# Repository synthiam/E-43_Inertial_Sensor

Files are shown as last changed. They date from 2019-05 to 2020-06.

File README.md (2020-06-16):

# E-43 Inertial Sensor

**Project Status:** Ready to manufacture

If you are new to GitHub and would like to create a derivative of this project, please have a look at GitHub instructions to [fork a repo](https://help.github.com/en/articles/fork-a-repo)

## Description

Out of our passion to solve the issue of time waste in the robot creation process, ARC was born. The ARC software platform reduces the time it takes to get from idea to implementation. Since 2011 we have been listening to the challenges robot builders encounter and continue to provide them with an ever expanding toolbox of solutions. Join us on this journey!

We didn't stop at the software, we also made time saving hardware solutions. This is an accelerometer/gyro/temperature sensor paired with an STM32 ARM cortex-M0 microcontroller. The microcontroller simplifies the sensor data and makes it compatible with ARC. A unique feature of this design is that it connects directly to a visual interface and automatically outputs pitch and roll angles in ARC. We want to share these files with you so you can create your own version for your community and customers to enjoy!

**Features:** 
- 3-axis Gyroscope/Accelerometer
- Temperature sensor
- I2C communication
- Mini programming header
- 5V tolerant I/O pins
- Blue LED status indicator
- ARC skill available 
- Voltage requirement: 3.2-3.4VDC (3.3V Typical)
- Current draw: 10.8mA
- Dimensions: 15.8(W) x 38.7(L) x 7.5(H) (mm)
- Weight: 3g

**Major components:** 
- STM32F030C8T6 32-bit Cortex-M0 ARM microcontroller (custom firmware provided)
- LSM6DS3USTR Accelerometer/Gyro Combo 

**Manufacturing notes:** 
1. Supplier: programs custom firmware into the STM32F030C8T6 at their facility before sending to manufacturer
2. Manufacturer: Single side placement and soldering of SMT components

## Contents

[**Documentation:**](https://github.com/synthiam/E-43_Inertial_Sensor/tree/master/E-43%20Documentation) Schematic PDF, Datasheet PDF, BOM, Test Procedures

[**Hardware:**](https://github.com/synthiam/E-43_Inertial_Sensor/tree/master/E-43%20Hardware) Altium PCB design File, Altium SCH Design File, Gerbers

[**Firmware:**](https://github.com/synthiam/E-43_Inertial_Sensor/tree/master/E-43%20Firmware) Code, Compiled Binary

*Altium Libraries are also available <a href="https://github.com/synthiam/Synthiam_Altium_Librairies">here</a>*

## Photos

<p align="left">

</p>

## Contact

For profit use of these files requires written consent. Contact partners@synthiam.com. For everyone else, party on!

For support check out our Synthiam Community: https://synthiam.com/Community

## License

This project is released under the following licenses:

**Hardware:** Creative Commons Plus Attribution-NonCommercial 4.0 International (CC+ BY-NC 4.0)

**Firmware:** Apache 2.0 + “Commons Clause” License Condition v1.0

Please see [LICENSE.md](https://github.com/synthiam/E-43_Inertial_Sensor/blob/master/LICENSE.md) for license details.



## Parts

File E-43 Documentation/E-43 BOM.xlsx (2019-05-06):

Qty | Description | Manufacturer Part No. | Alternative | Designator | Custom Information | Link
E-43 Interial Sensor
1 | 2 layer, Blue soldermask, White silkscreen, ENIG | Inertial Sensor Board |  | PCB
1 | STmicro MCU 32bit 64KB Flash 48LQFP | STM32F030C8T6 |  | U1 | Needs custom Firmware programmed into chip | https://www.digikey.ca/product-detail/en/stmicroelectronics/STM32F030C8T6/497-14043-ND/4357252
1 | White 0805 LED | QBLP631-IW |  | LED |  | http://www.digikey.ca/product-detail/en/0/1516-1085-1-ND
4 | 0.1uF 0603 Ceramic Capacitor | C0603C104K4RACTU |  | C1, C2, C3, C4
2 | FERRITE BEAD 30 OHM 0603 | CIC10P300NC |  | L1, L2 |  | https://www.digikey.ca/product-detail/en/samsung-electro-mechanics/CIC10P300NC/1276-6322-1-ND/3973802
2 | 4.7kohm 4 x Resistor Array | EXB-38V472JV |  | RA1, RA2
1 | 330ohm Resistor 0603 1/10W | RC0603FR-07330RL |  | R1
1 | STmicro Accelerometer/Gyro Combo | LSM6DS3USTR |  | U2 |  | https://www.digikey.ca/product-detail/en/stmicroelectronics/LSM6DS3USTR/497-16910-1-ND/6229964
1 | 4-pin 2mm pitch JST-PH SMD connector | S4B-PH-SM4-TB(LF)(SN) |  | P1 |  | http://www.digikey.ca/product-detail/en/S4B-PH-SM4-TB(LF)(SN)/455-1751-1-ND/926848

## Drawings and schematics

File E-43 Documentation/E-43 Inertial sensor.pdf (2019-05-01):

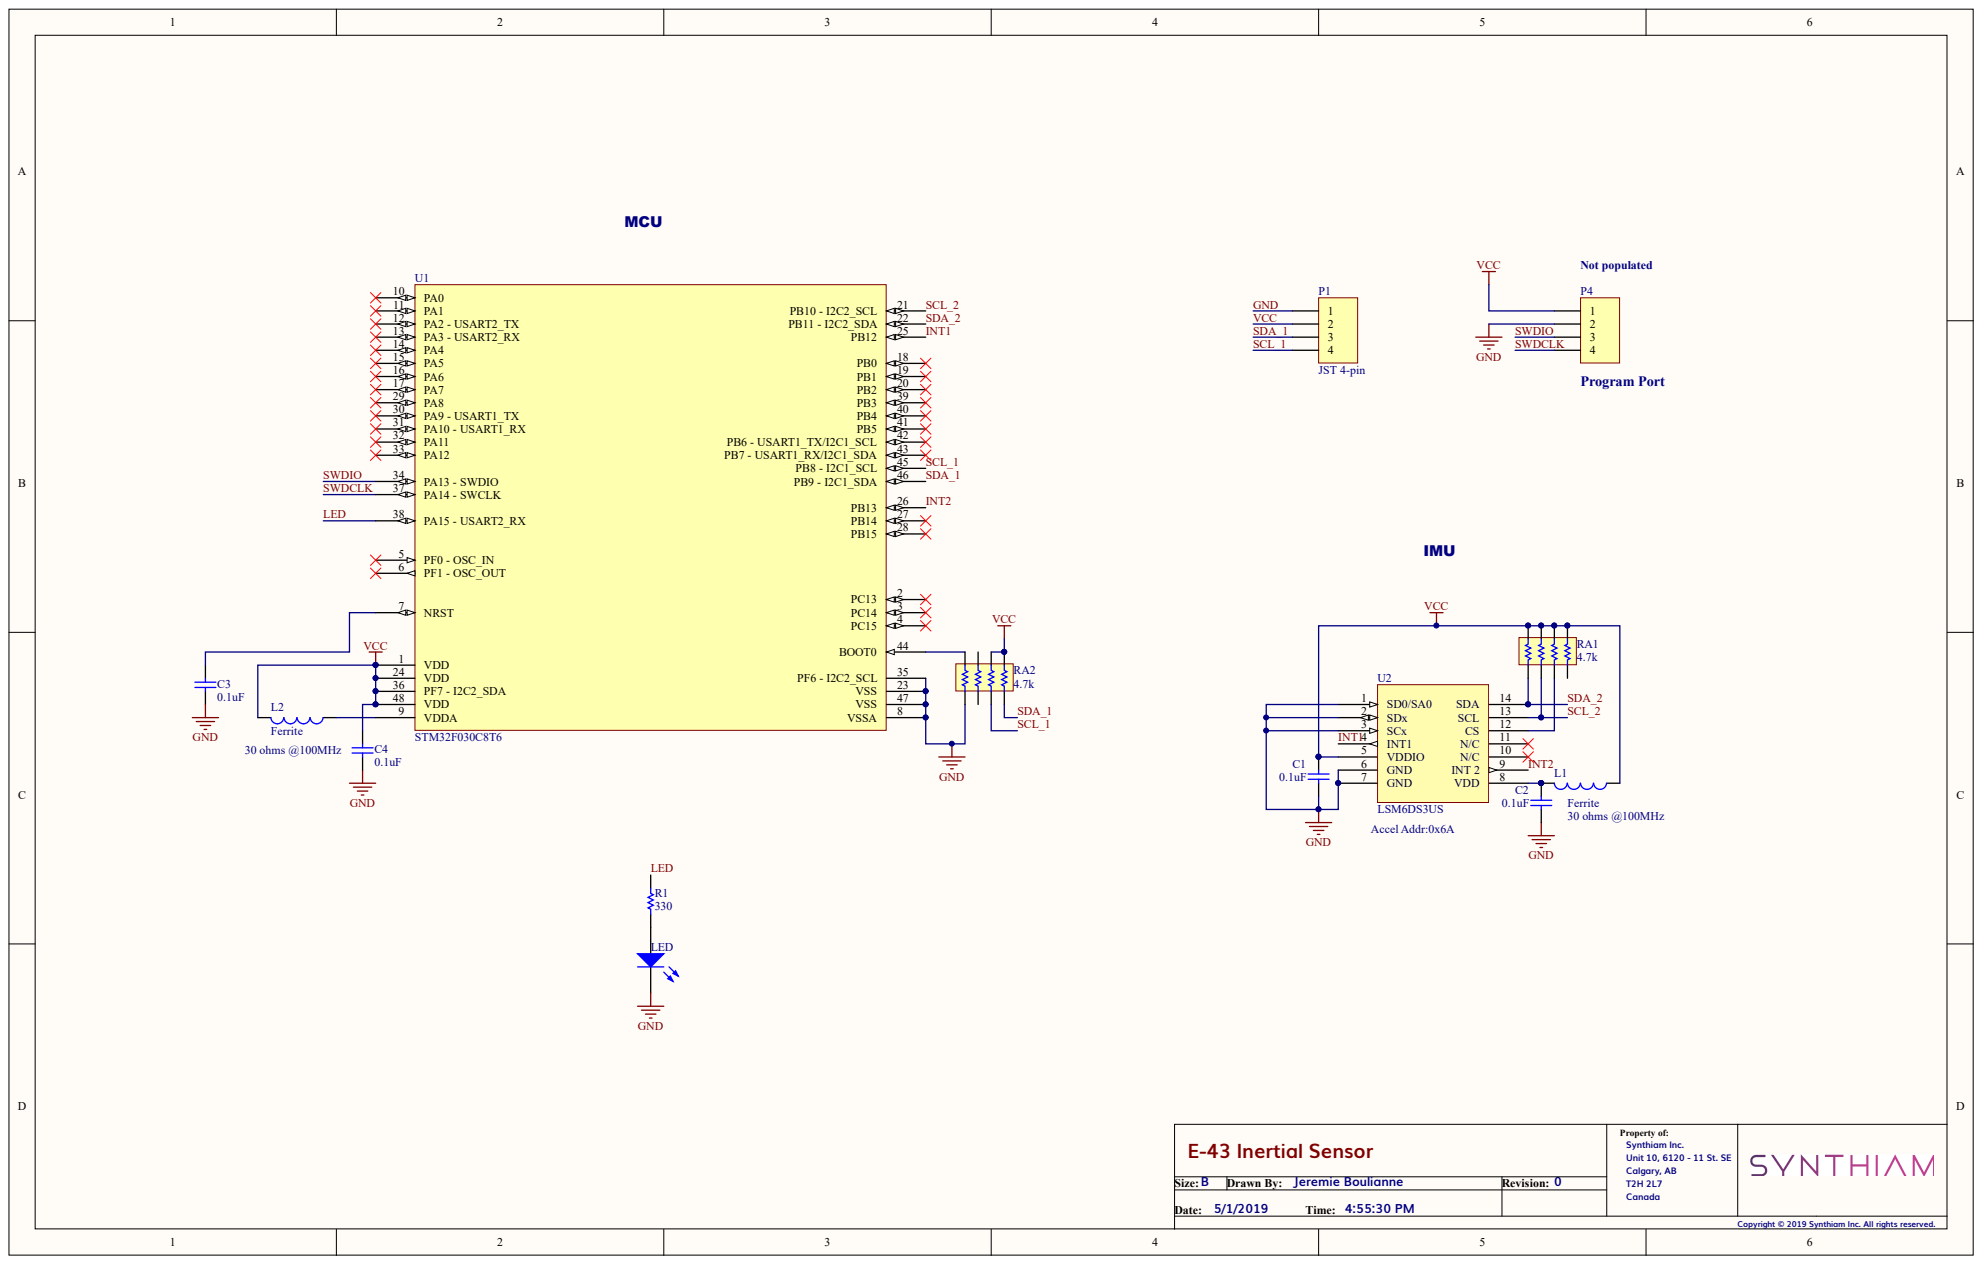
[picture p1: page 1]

VDD 1
VDD 24

E-43 Inertial Sensor | Property of: Synthiam Inc. Unit 10, 6120 - 11 St. SE Calgary, AB T2H 2L7 Canada

B Size: | Jeremie Boulianne Drawn By: | 0 Revision:
5/1/2019 4:55:30 PM Date: Time:

Copyright © 2019 Synthiam Inc. All rights reserved.

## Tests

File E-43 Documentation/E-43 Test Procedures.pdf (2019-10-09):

# E-43 Test Procedures

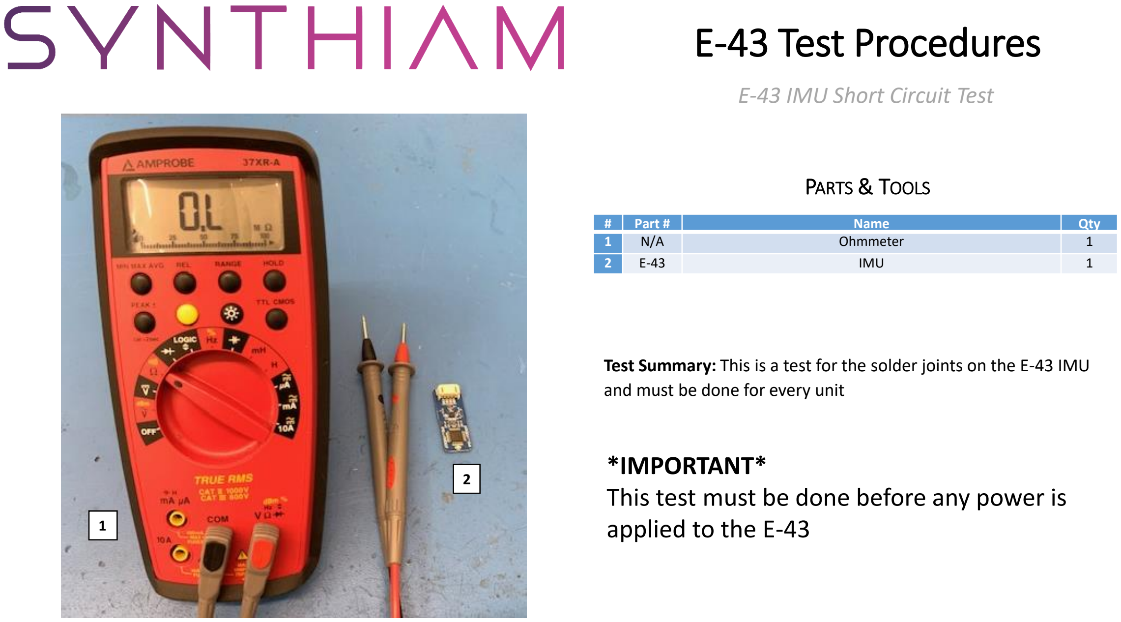
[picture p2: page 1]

# | Part # | Name | Qty

1 | N/A | Ohmmeter | 1
2 | E-43 | IMU | 1

E-43 IMU Short Circuit Test

PARTS & TOOLS

Test Summary: This is a test for the solder joints on the E-43 IMU and must be done for every unit

*IMPORTANT*
This test must be done before any power is

### 1 applied to the E-43

2

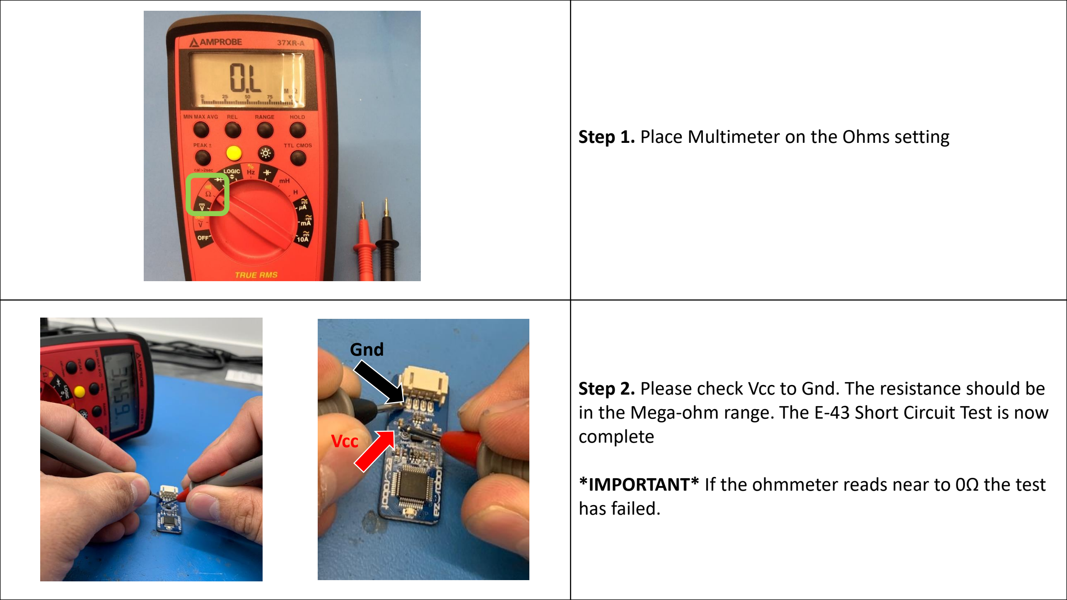
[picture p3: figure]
complete; has failed.; Vcc; Gnd

Step 1. Place Multimeter on the Ohms setting
Step 2. Please check Vcc to Gnd. The resistance should be in the Mega-ohm range. The E-43 Short Circuit Test is now

*IMPORTANT* If the ohmmeter reads near to 0Ω the test

# E-43 Test Procedures

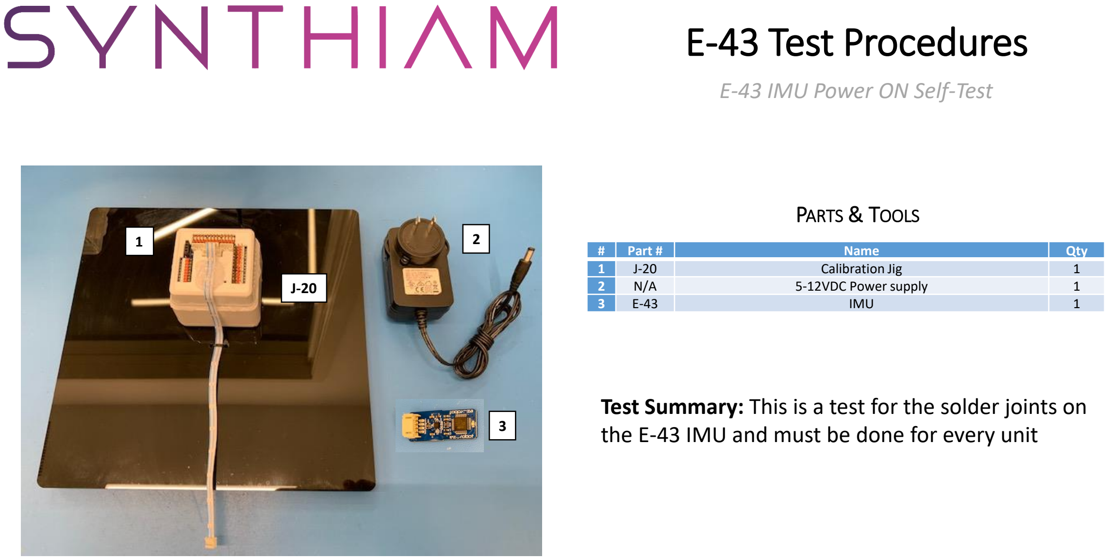
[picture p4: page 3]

# | Part # | Name | Qty

1 | J-20 | Calibration Jig | 1
2 | N/A | 5-12VDC Power supply | 1
3 | E-43 | IMU | 1

E-43 IMU Power ON Self-Test

PARTS & TOOLS

1 2

3

J-20

Test Summary: This is a test for the solder joints on the E-43 IMU and must be done for every unit

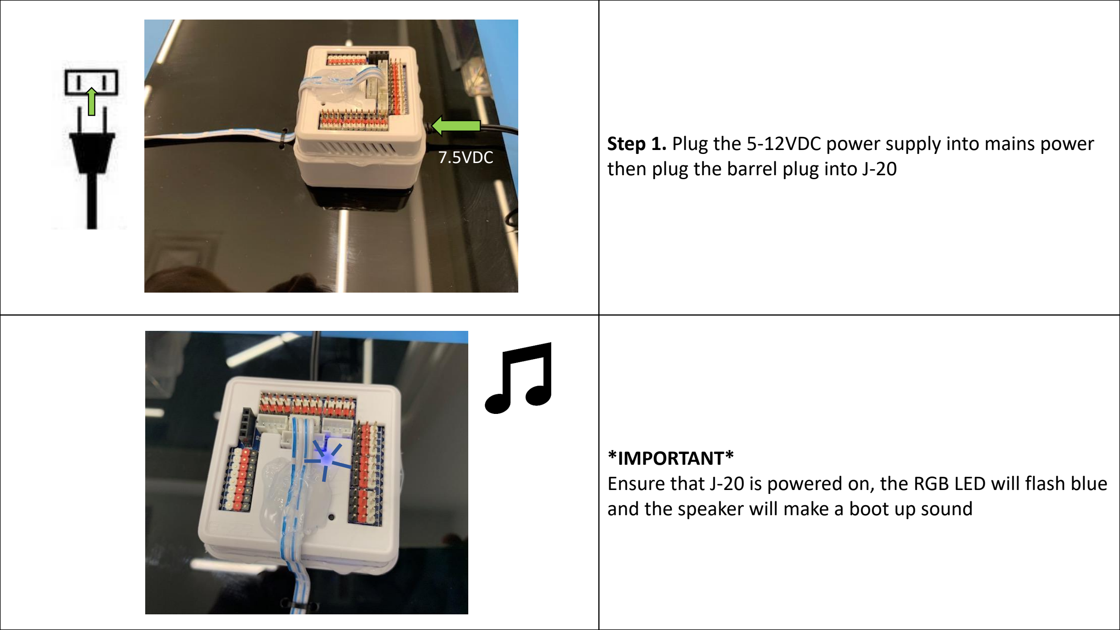
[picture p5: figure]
then plug the barrel plug into J-20; *IMPORTANT*; 7.5VDC

Step 1. Plug the 5-12VDC power supply into mains power

Ensure that J-20 is powered on, the RGB LED will flash blue and the speaker will make a boot up sound

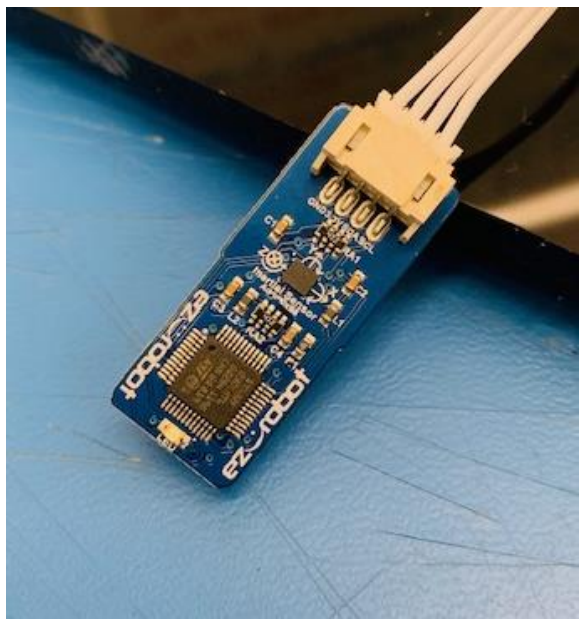
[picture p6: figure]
5-12VDC
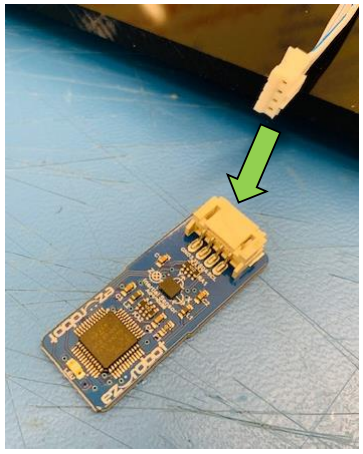
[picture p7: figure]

Step 2. Plug the TP-101 cable from J-21 into E-43

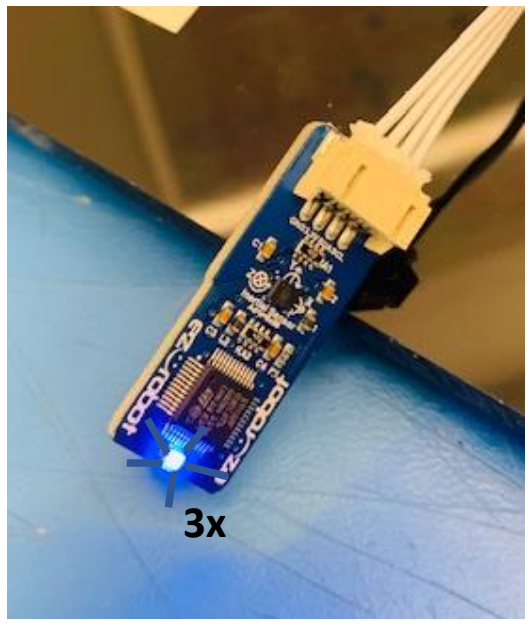
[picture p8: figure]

Step 3. Wait 1 second for the E-43 boot, the LED will blink 3 times and then turn OFF

*IMPORTANT* If the LED stays ON or if the LED doesn’t blink at all the test has failed, the LSM6DS sensor may need to be reflowed

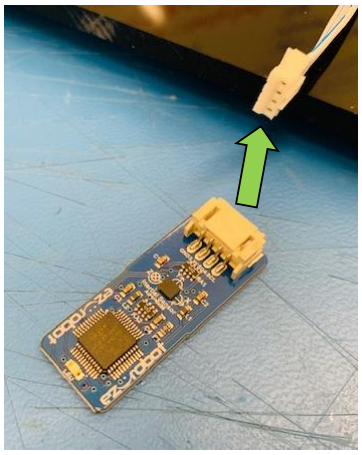
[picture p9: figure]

Step 4. Remove E-43 from TP-101. The E-43 Power ON Self-Test is now complete

5-12VDC

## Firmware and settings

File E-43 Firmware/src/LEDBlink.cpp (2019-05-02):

#include <stm32f0xx_gpio.h>
#include <stm32f0xx_rcc.h>
#include <stm32f0xx_usart.h>
#include <stm32f0xx_dma.h>
#include <stm32f0xx_misc.h>
#include <stm32f0xx_i2c.h>
#include <stm32f0xx_tim.h>
#include <stm32f0xx_exti.h>
#include <stm32f0xx_syscfg.h>
#include <math.h>
#include "EZUtils.h"

#define I2C_TIMEOUT_MAX 1000

#define IMU_ADDRESS (0x6A << 1)
#define IMU_CMD_BUFFER_SIZE 14

#define MY_ADDRESS 0xC8

volatile uint8_t _IMUBuffer[IMU_CMD_BUFFER_SIZE];

void delay() {

  int i;

  for (i = 0; i < 600000; i++)
    asm("nop");
}

void BlueAlternateLED() {

  if (GPIO_ReadOutputDataBit(GPIOA, GPIO_Pin_15))
    GPIO_WriteBit(GPIOA, GPIO_Pin_15, Bit_RESET);
  else
    GPIO_WriteBit(GPIOA, GPIO_Pin_15, Bit_SET);
}

void BlueLED(bool status) {

  GPIO_WriteBit(GPIOA, GPIO_Pin_15, (BitAction)!status);
}

int8_t I2CRead(uint8_t reg, uint8_t *buffer, uint8_t bufferStartIndex, uint8_t bytesToRead) {

  uint8_t singleData = 0;

  // Wait until I2C isn't busy
  while (I2C_GetFlagStatus(I2C2, I2C_ISR_BUSY) == SET);

  I2C_TransferHandling(I2C2, IMU_ADDRESS, 1, I2C_SoftEnd_Mode, I2C_Generate_Start_Write);

  // Ensure the transmit interrupted flag is set
  while (I2C_GetFlagStatus(I2C2, I2C_ISR_TXIS) == RESET);

  // Send the address of the register we wish to write to
  I2C_SendData(I2C2, (uint8_t)reg);

  // Ensure the transmit interrupted flag is set
  while (I2C_GetFlagStatus(I2C2, I2C_ISR_TC) == RESET);

  I2C_TransferHandling(I2C2, IMU_ADDRESS + 1, bytesToRead, I2C_AutoEnd_Mode, I2C_Generate_Start_Read);

  for (uint8_t cnt = 0; cnt < bytesToRead; cnt++) {

    while (I2C_GetFlagStatus(I2C2, I2C_ISR_RXNE) == RESET);

    // If we're only reading one byte, place that data direct into the  SingleData variable. 
    // If we're reading more than 1 piece of data store in the array "Data" (a pointer from main) 		
    if (bytesToRead > 1)
      buffer[bufferStartIndex + cnt] = I2C_ReceiveData(I2C2);
    else
      singleData = I2C_ReceiveData(I2C2);
  }

  while (I2C_GetFlagStatus(I2C2, I2C_ISR_STOPF) == RESET);

  // Clear the stop flag for the next potential transfer
  I2C_ClearFlag(I2C2, I2C_FLAG_STOPF);

  // Return a single piece of data if DCnt was less than 1, otherwise 0 will be returned.
  return singleData;
}

void I2CSend(uint8_t Reg, uint8_t Val) {

  //Wait until I2C isn't busy
  while (I2C_GetFlagStatus(I2C2, I2C_FLAG_BUSY) == SET);

  I2C_TransferHandling(I2C2, IMU_ADDRESS, 1, I2C_Reload_Mode, I2C_Generate_Start_Write);

  //Ensure the transmit interrupted flag is set
  while (I2C_GetFlagStatus(I2C2, I2C_ISR_TXIS) == RESET);

  //Send the address of the register we wish to write to
  I2C_SendData(I2C2, (uint8_t)Reg);

  //Ensure the transmit interrupted flag is set
  while (I2C_GetFlagStatus(I2C2, I2C_ISR_TCR) == RESET);

  I2C_TransferHandling(I2C2, IMU_ADDRESS, 1, I2C_AutoEnd_Mode, I2C_No_StartStop);

  //Again, wait until the transmit interrupted flag is set
  while (I2C_GetFlagStatus(I2C2, I2C_ISR_TXIS) == RESET);

  //Send the value you wish you write to the register
  I2C_SendData(I2C2, Val);

  while (I2C_GetFlagStatus(I2C2, I2C_ISR_STOPF) == RESET);

  //Clear the stop flag for the next potential transfer
  I2C_ClearFlag(I2C2, I2C_ISR_STOPF);
}

int _WRITE_POS = 0;

#define STUPID_DELAY 2000

extern "C" void I2C1_IRQHandler() {

  BlueAlternateLED();

  if (I2C_GetITStatus(I2C1, I2C_IT_ADDR)) {

    I2C_ClearITPendingBit(I2C1, I2C_IT_ADDR);

    if (I2C_GetTransferDirection(I2C1) == I2C_Direction_Receiver) {

      // Request for us to begin writing

      _WRITE_POS = 0;

      I2C_SendData(I2C1, _IMUBuffer[_WRITE_POS++]);
    }
    else {

      _WRITE_POS = 0;

      // Get the address, which is our own
      uint8_t tmp = I2C_GetAddressMatched(I2C1);
    }
  }

  if (I2C_GetITStatus(I2C1, I2C_IT_RXNE)) {

    // data was sent to us, let's receive it and reset the position to write memory from

    _WRITE_POS = 0;

    uint8_t tmp = I2C_ReceiveData(I2C1);
  }

  if (I2C_GetITStatus(I2C1, I2C_IT_TXIS)) {

    if (_WRITE_POS >= IMU_CMD_BUFFER_SIZE)
      _WRITE_POS = 0;

    I2C_SendData(I2C1, _IMUBuffer[_WRITE_POS++]);
  }

  if (I2C_GetITStatus(I2C1, I2C_IT_NACKF)) 
    I2C_ClearITPendingBit(I2C1, I2C_IT_NACKF);
  
  if (I2C_GetITStatus(I2C1, I2C_IT_STOPF)) {

    _WRITE_POS = 0;

    I2C_ClearITPendingBit(I2C1, I2C_IT_STOPF);
  }

  if (I2C_GetITStatus(I2C1, I2C_IT_BERR)) 
    I2C_ClearITPendingBit(I2C1, I2C_IT_BERR);
  
  if (I2C_GetITStatus(I2C1, I2C_IT_ARLO)) 
    I2C_ClearITPendingBit(I2C1, I2C_IT_ARLO);

  if (I2C_GetITStatus(I2C1, I2C_IT_OVR)) 
    I2C_ClearITPendingBit(I2C1, I2C_IT_OVR);
}

int main() {

  DelayMS(100);

  GPIO_InitTypeDef GPIO_InitStructure;
  DMA_InitTypeDef DMA_InitStructure;
  I2C_InitTypeDef i2cInitStructure;
  NVIC_InitTypeDef NVIC_InitStructure;

  // Clocks
  // -------------------------------------------------------------------------------------------------
  RCC_APB2PeriphClockCmd(RCC_APB2Periph_SYSCFG, ENABLE);
  RCC_AHBPeriphClockCmd(RCC_AHBPeriph_GPIOA, ENABLE);
  RCC_AHBPeriphClockCmd(RCC_AHBPeriph_GPIOB, ENABLE);
  RCC_APB1PeriphClockCmd(RCC_APB1Periph_I2C2, ENABLE);
  RCC_APB1PeriphClockCmd(RCC_APB1Periph_I2C1, ENABLE);

  // Interrupt 1 (accel)
  // -------------------------------------------------------------------------------------------------
  GPIO_InitStructure.GPIO_Pin = GPIO_Pin_12;
  GPIO_InitStructure.GPIO_Mode = GPIO_Mode_IN;
  GPIO_InitStructure.GPIO_OType = GPIO_OType_PP;
  GPIO_InitStructure.GPIO_PuPd = GPIO_PuPd_DOWN;
  GPIO_InitStructure.GPIO_Speed = GPIO_Speed_50MHz;
  GPIO_Init(GPIOB, &GPIO_InitStructure);

  // Interrupt 2 (gyro)
  // -------------------------------------------------------------------------------------------------
  GPIO_InitStructure.GPIO_Pin = GPIO_Pin_13;
  GPIO_InitStructure.GPIO_Mode = GPIO_Mode_IN;
  GPIO_InitStructure.GPIO_OType = GPIO_OType_PP;
  GPIO_InitStructure.GPIO_PuPd = GPIO_PuPd_DOWN;
  GPIO_InitStructure.GPIO_Speed = GPIO_Speed_50MHz;
  GPIO_Init(GPIOB, &GPIO_InitStructure);

  // BLUE LED
  // -------------------------------------------------------------------------------------------------
  GPIO_InitStructure.GPIO_Pin = GPIO_Pin_15;
  GPIO_InitStructure.GPIO_Mode = GPIO_Mode_OUT;
  GPIO_InitStructure.GPIO_OType = GPIO_OType_PP;
  GPIO_InitStructure.GPIO_PuPd = GPIO_PuPd_NOPULL;
  GPIO_InitStructure.GPIO_Speed = GPIO_Speed_50MHz;
  GPIO_Init(GPIOA, &GPIO_InitStructure);
  BlueLED(false);

  // i2c EZ-B
  // -------------------------------------------------------------------------------------------------

  I2C_DeInit(I2C1);

  // SCL
  GPIO_InitStructure.GPIO_Pin = GPIO_Pin_8;
  GPIO_InitStructure.GPIO_Mode = GPIO_Mode_AF;
  GPIO_InitStructure.GPIO_OType = GPIO_OType_OD;
  GPIO_InitStructure.GPIO_PuPd = GPIO_PuPd_UP;
  GPIO_InitStructure.GPIO_Speed = GPIO_Speed_50MHz;
  GPIO_Init(GPIOB, &GPIO_InitStructure);

  // SDA
  GPIO_InitStructure.GPIO_Pin = GPIO_Pin_9;
  GPIO_InitStructure.GPIO_Mode = GPIO_Mode_AF;
  GPIO_InitStructure.GPIO_OType = GPIO_OType_OD;
  GPIO_InitStructure.GPIO_PuPd = GPIO_PuPd_UP;
  GPIO_InitStructure.GPIO_Speed = GPIO_Speed_50MHz;
  GPIO_Init(GPIOB, &GPIO_InitStructure);

  RCC_I2CCLKConfig(RCC_I2C1CLK_SYSCLK);

  GPIO_PinAFConfig(GPIOB, GPIO_PinSource8, GPIO_AF_1);
  GPIO_PinAFConfig(GPIOB, GPIO_PinSource9, GPIO_AF_1);

  I2C_StructInit(&i2cInitStructure);
  i2cInitStructure.I2C_OwnAddress1 = MY_ADDRESS;
  i2cInitStructure.I2C_Timing = 0x10800000;
  I2C_Init(I2C1, &i2cInitStructure);

  NVIC_InitStructure.NVIC_IRQChannel = I2C1_IRQn;
  NVIC_InitStructure.NVIC_IRQChannelPriority = 0;
  NVIC_InitStructure.NVIC_IRQChannelCmd = ENABLE;
  NVIC_Init(&NVIC_InitStructure);

  I2C_ITConfig(I2C1, (I2C_IT_ERRI | I2C_IT_STOPI | I2C_IT_ADDRI | I2C_IT_RXI | I2C_IT_TXI), ENABLE);

  I2C_Cmd(I2C1, ENABLE);

  // I2C IMU
  // -------------------------------------------------------------------------------------------------

  I2C_DeInit(I2C2);

  // SCL
  GPIO_InitStructure.GPIO_Pin = GPIO_Pin_10;
  GPIO_InitStructure.GPIO_Mode = GPIO_Mode_AF;
  GPIO_InitStructure.GPIO_OType = GPIO_OType_OD;
  GPIO_InitStructure.GPIO_PuPd = GPIO_PuPd_UP;
  GPIO_InitStructure.GPIO_Speed = GPIO_Speed_50MHz;
  GPIO_Init(GPIOB, &GPIO_InitStructure);

  // SDA
  GPIO_InitStructure.GPIO_Pin = GPIO_Pin_11;
  GPIO_InitStructure.GPIO_Mode = GPIO_Mode_AF;
  GPIO_InitStructure.GPIO_OType = GPIO_OType_OD;
  GPIO_InitStructure.GPIO_PuPd = GPIO_PuPd_UP;
  GPIO_InitStructure.GPIO_Speed = GPIO_Speed_50MHz;
  GPIO_Init(GPIOB, &GPIO_InitStructure);

  GPIO_PinAFConfig(GPIOB, GPIO_PinSource10, GPIO_AF_1);
  GPIO_PinAFConfig(GPIOB, GPIO_PinSource11, GPIO_AF_1);

  I2C_StructInit(&i2cInitStructure);
  i2cInitStructure.I2C_Timing = 0x10805E89;
  I2C_Init(I2C2, &i2cInitStructure);

  I2C_Cmd(I2C2, ENABLE);

  // Initialize IMU
  // -------------------------------------------------------------------------------------------------
  // #CTRL9_XL = 0x38 Acc X,Y,Z enabled
  I2CSend(0x18, 0x38);

  // #CTRL1_XL = 0x60 Acc = 416Hz High performance mode, +8g, 400hz anti alias
  I2CSend(0x10, 0x6F); //c

  // #INT1_CTRL = 0x01 Acc data ready interrupt on INT1
  I2CSend(0x0d, 0x01);

  // #CTRL10_C = 0x38 Gyro X,Y,Z enabled
  I2CSend(0x19, 0x38);

  // #CTRL2_G = 0x60 Gyro = 416Hz High performance mode
  I2CSend(0x11, 0x6C);

  // #INT2_CTRL = 0x02 Gyro data ready interrupt on INT2
  I2CSend(0x0e, 0x02);

  for (int x = 1; x < 8; x++) {

    BlueAlternateLED();

    DelayMS(25);
  }

  // Program Loop
  // -------------------------------------------------------------------------------------------------
  while (true) {

    // Gyro (INT2)
    if (GPIO_ReadInputDataBit(GPIOB, GPIO_Pin_13))
      I2CRead(0x20, (uint8_t *)_IMUBuffer, 0, 8);

    // Accel (INT1)
    if (GPIO_ReadInputDataBit(GPIOB, GPIO_Pin_12))
      I2CRead(0x28, (uint8_t *)_IMUBuffer, 8, 6);
  }
}
